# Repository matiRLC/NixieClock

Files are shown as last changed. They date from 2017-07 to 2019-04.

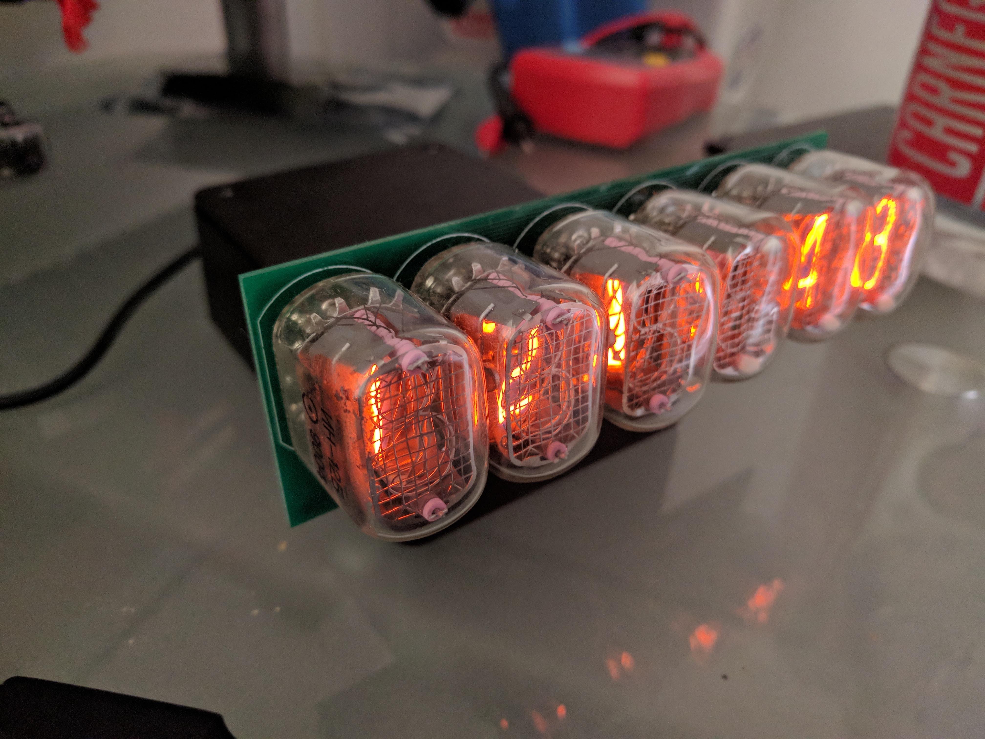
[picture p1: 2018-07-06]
docs/nixieclock5.jpg

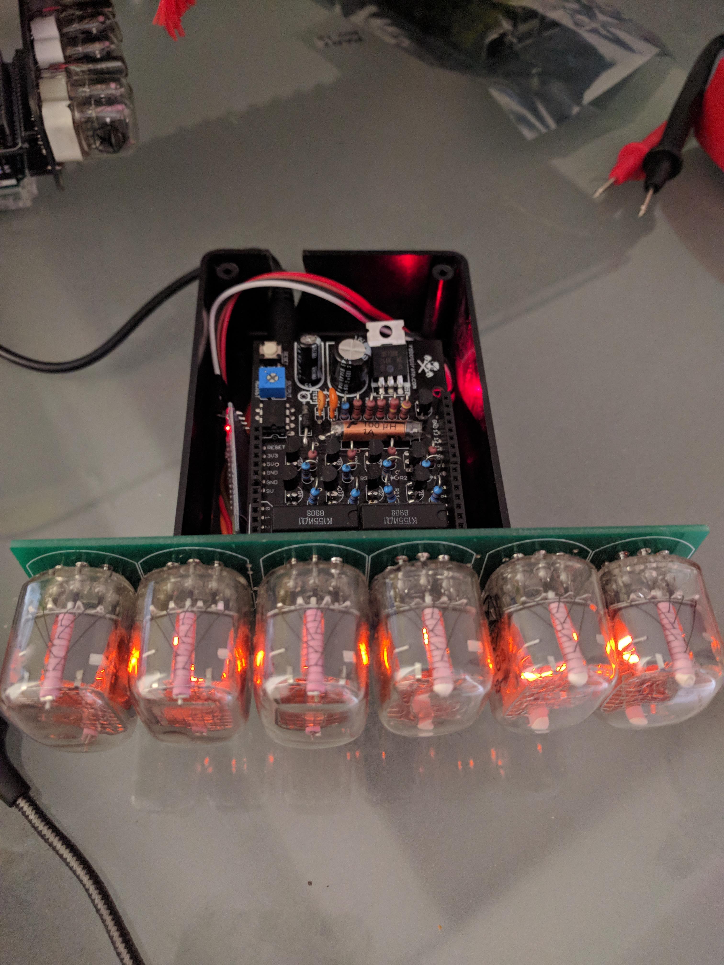
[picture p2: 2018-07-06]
docs/nixieclock4.jpg

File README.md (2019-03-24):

View this project on [CADLAB.io](https://cadlab.io/project/1200). 

# NixieClock
Nixie Tube Clock based project based on existing code and boards by Ogilumen and RobotPirate

The current project uses an Arduino Uno and the Arduinix Shield from RobotPirate. The code is an extension of the sample code
provided by the latter. The PCB for 6 nixie tubes was designed based on the .pdf schematic available in [Arduinix](http://www.arduinix.com).

As of 2019, the current design uses a bluetooth module (HC-06 or HM-10). The use of HM-10 was chosen since it's a Bluetooth 4.0+ module that allows it to work with both Android and iOS apps.

The iOS app was implemented with the work from [hoiberg](https://github.com/hoiberg/HM10-BluetoothSerial-iOS) as a template. His explanation of his project can be found [here](http://www.hangar42.nl/hm10).

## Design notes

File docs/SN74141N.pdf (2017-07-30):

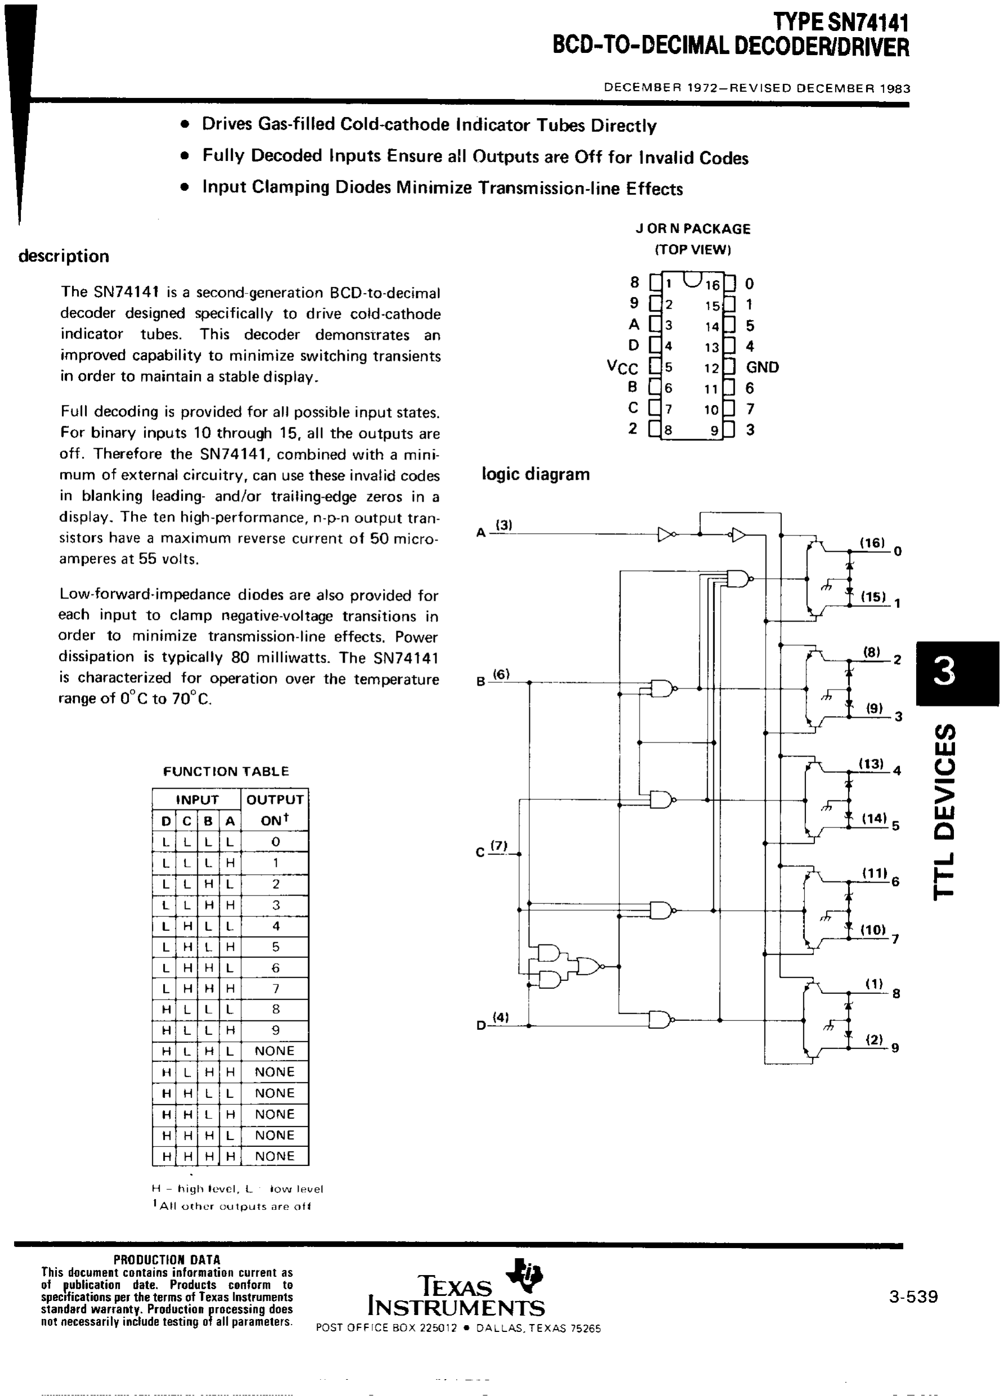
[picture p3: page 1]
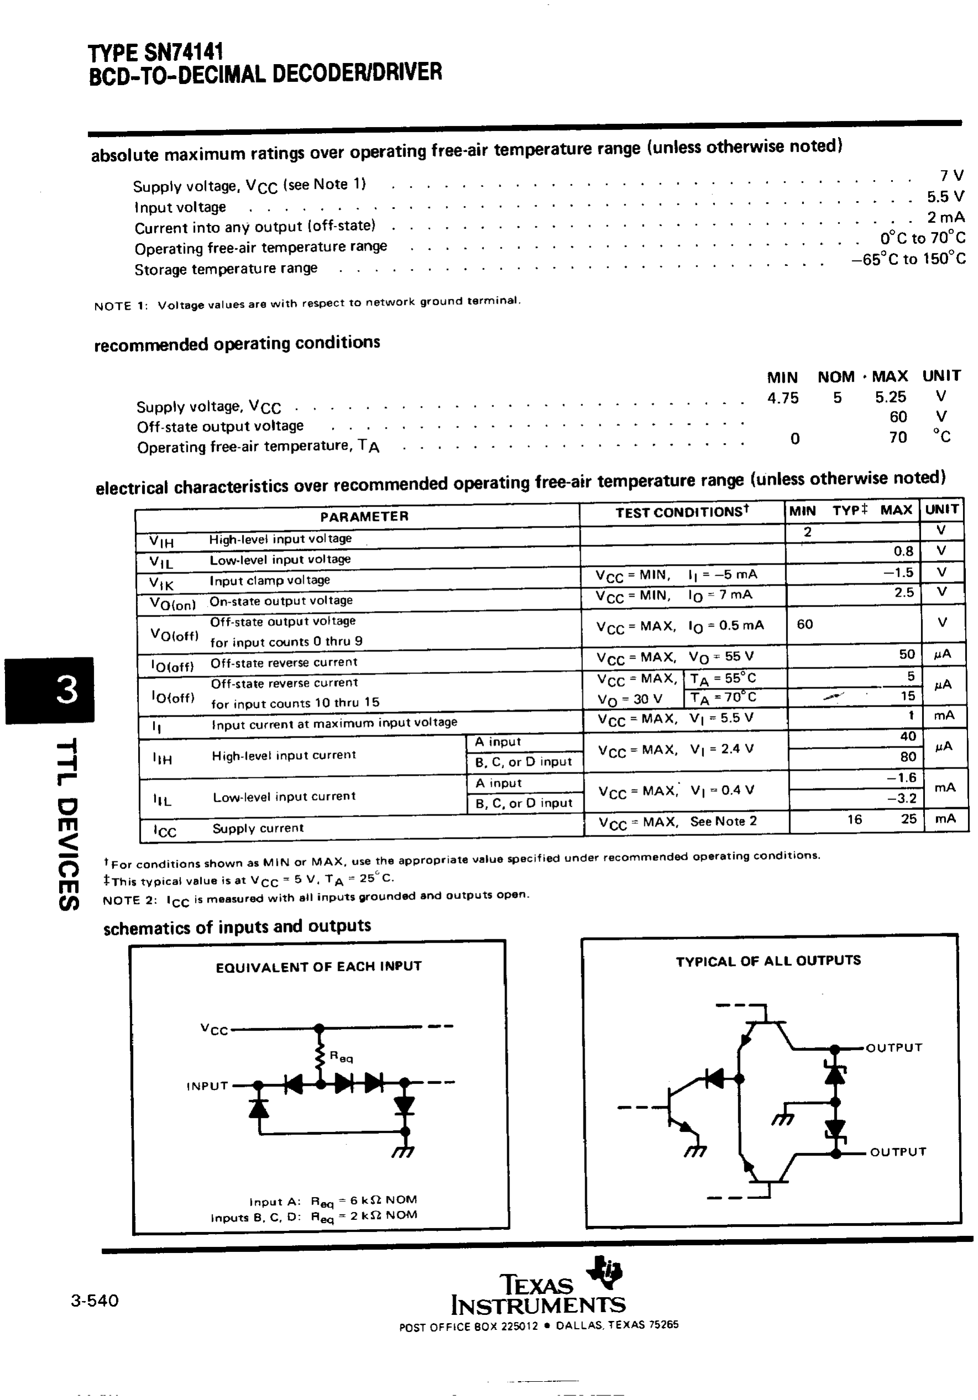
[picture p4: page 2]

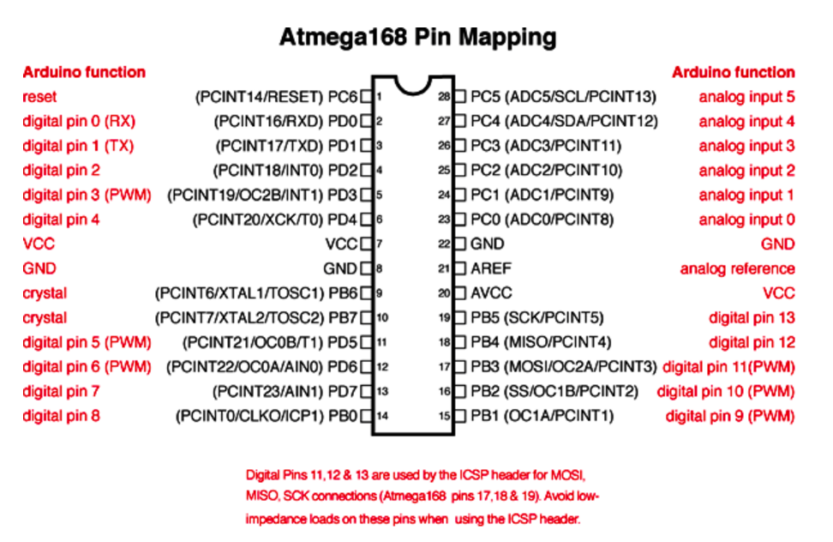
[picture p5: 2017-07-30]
docs/Arduino Atmel pinout.png

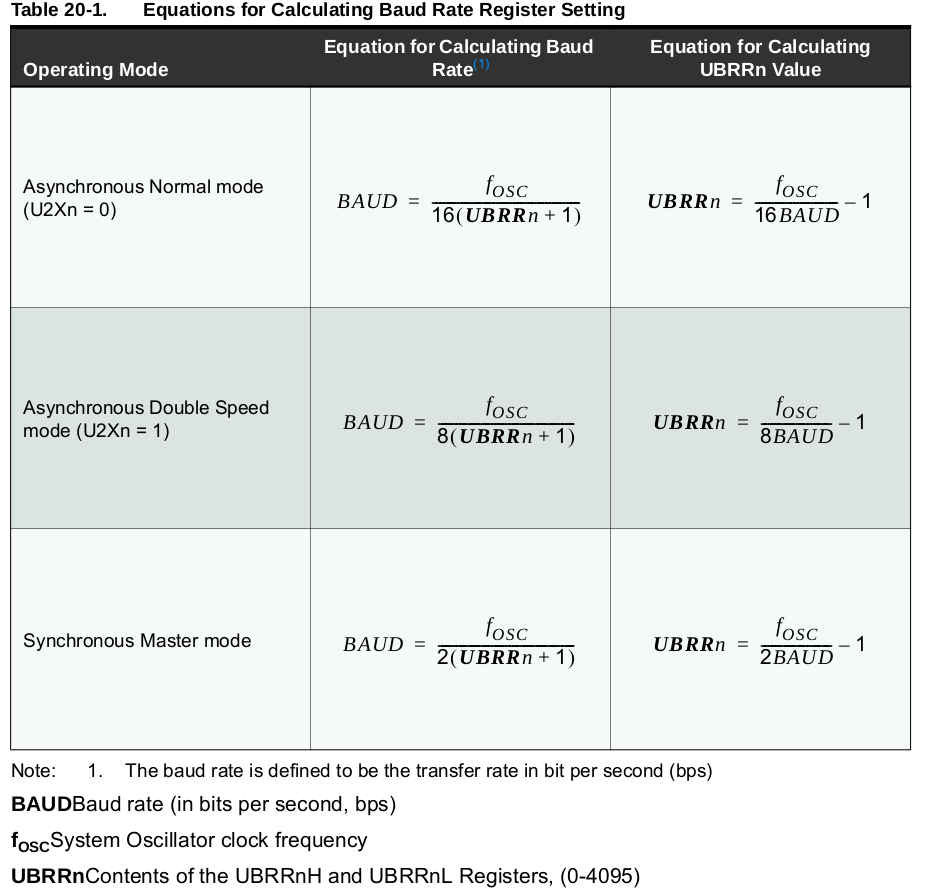
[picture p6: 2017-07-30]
docs/Baud Rates Register Setting.png

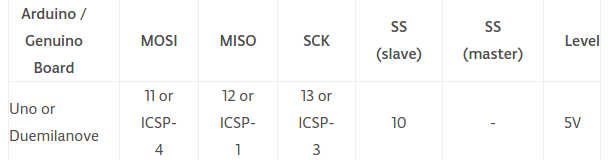
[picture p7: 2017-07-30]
docs/SPI Pins.png

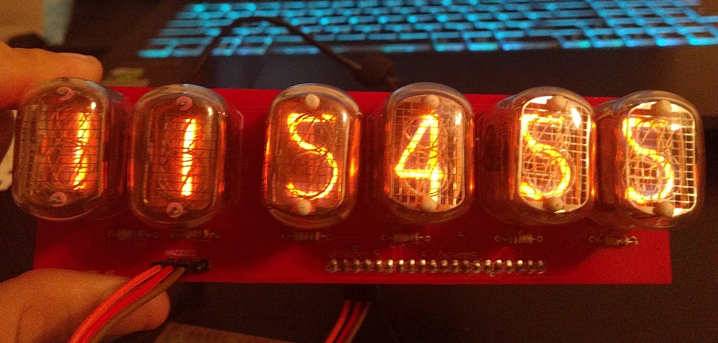
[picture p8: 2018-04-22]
docs/nixieclock_teaser.jpg

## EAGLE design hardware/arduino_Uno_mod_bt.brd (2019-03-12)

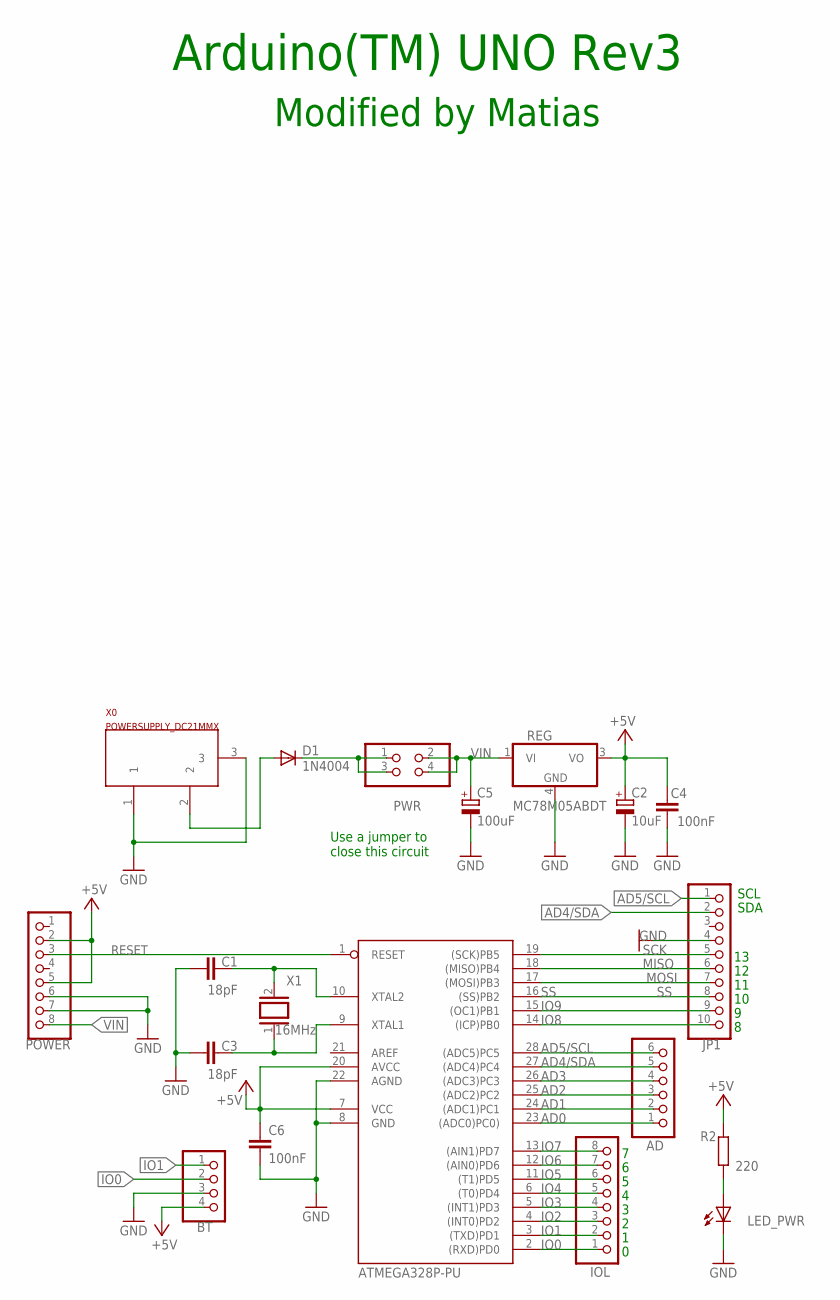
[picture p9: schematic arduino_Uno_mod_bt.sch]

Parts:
AD: 6x1F-H8.5; 1X06
BT: PINHD-1X4/90; 1X04/90
C1, C3: 18pF; C025-025X050
C2: 10uF; E2,5-5
C4, C6: 100nF; C025-025X050
C5: 100uF; E2-5
D1: 1N4004; DO41-10
IOL: 8x1F-H8.5; 1X08
JP1: PINHD-1X10; 1X10
LED_PWR: LED3MM
POWER: 8x1F-H8.5; 1X08
PWR: PINHD-2X2; 2X02
R2: 220; R1206
REG: MC78M05ABDT; DPACK_3
X0: POWERSUPPLY_DC21MMX; POWERSUPPLY_DC-21MM
X1: 16MHz; QS
ZU4: ATMEGA328P-PU; DIL28-3

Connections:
+5V: BT.4, C2.+, C4.2, C6.1, POWER.2, POWER.5, R2.2, REG.3 (VO), ZU4.7 (VCC), ZU4.20 (AVCC)
AD0: AD.1, ZU4.23 ((ADC0)PC0))
AD1: AD.2, ZU4.24 ((ADC1)PC1)
AD2: AD.3, ZU4.25 ((ADC2)PC2)
AD3: AD.4, ZU4.26 ((ADC3)PC3)
AD4/SDA: AD.5, JP1.2, ZU4.27 ((ADC4)PC4)
AD5/SCL: AD.6, JP1.1, ZU4.28 ((ADC5)PC5)
GND: BT.3, C1.1, C2.-, C3.1, C4.1, C5.-, C6.2, JP1.4, LED_PWR.K (C), POWER.6, POWER.7, REG.4 (GND), X0.1, X0.3, ZU4.8 (GND), ZU4.22 (AGND)
IN: D1.A, X0.2
IO0: BT.2, IOL.1, ZU4.2 ((RXD)PD0)
IO1: BT.1, IOL.2, ZU4.3 ((TXD)PD1)
IO2: IOL.3, ZU4.4 ((INT0)PD2)
IO3: IOL.4, ZU4.5 ((INT1)PD3)
IO4: IOL.5, ZU4.6 ((T0)PD4)
IO5: IOL.6, ZU4.11 ((T1)PD5)
IO6: IOL.7, ZU4.12 ((AIN0)PD6)
IO7: IOL.8, ZU4.13 ((AIN1)PD7)
IO8: JP1.10, ZU4.14 ((ICP)PB0)
IO9: JP1.9, ZU4.15 ((OC1)PB1)
MISO: JP1.6, ZU4.18 ((MISO)PB4)
MOSI: JP1.7, ZU4.17 ((MOSI)PB3)
unnamed: C3.2, X1.1, ZU4.9 (XTAL1)
unnamed: LED_PWR.A, R2.1
unnamed: D1.C, PWR.1, PWR.3
RESET: POWER.3, ZU4.1 (RESET)
SCK: JP1.5, ZU4.19 ((SCK)PB5)
SS: JP1.8, ZU4.16 ((SS)PB2)
VIN: C5.+, POWER.8, PWR.2, PWR.4, REG.1 (VI)
XTAL2: C1.2, X1.2, ZU4.10 (XTAL2)

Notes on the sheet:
Arduino(TM) UNO Rev3
SDA
SCL
Modified by Matias
Use a jumper to close this circuit

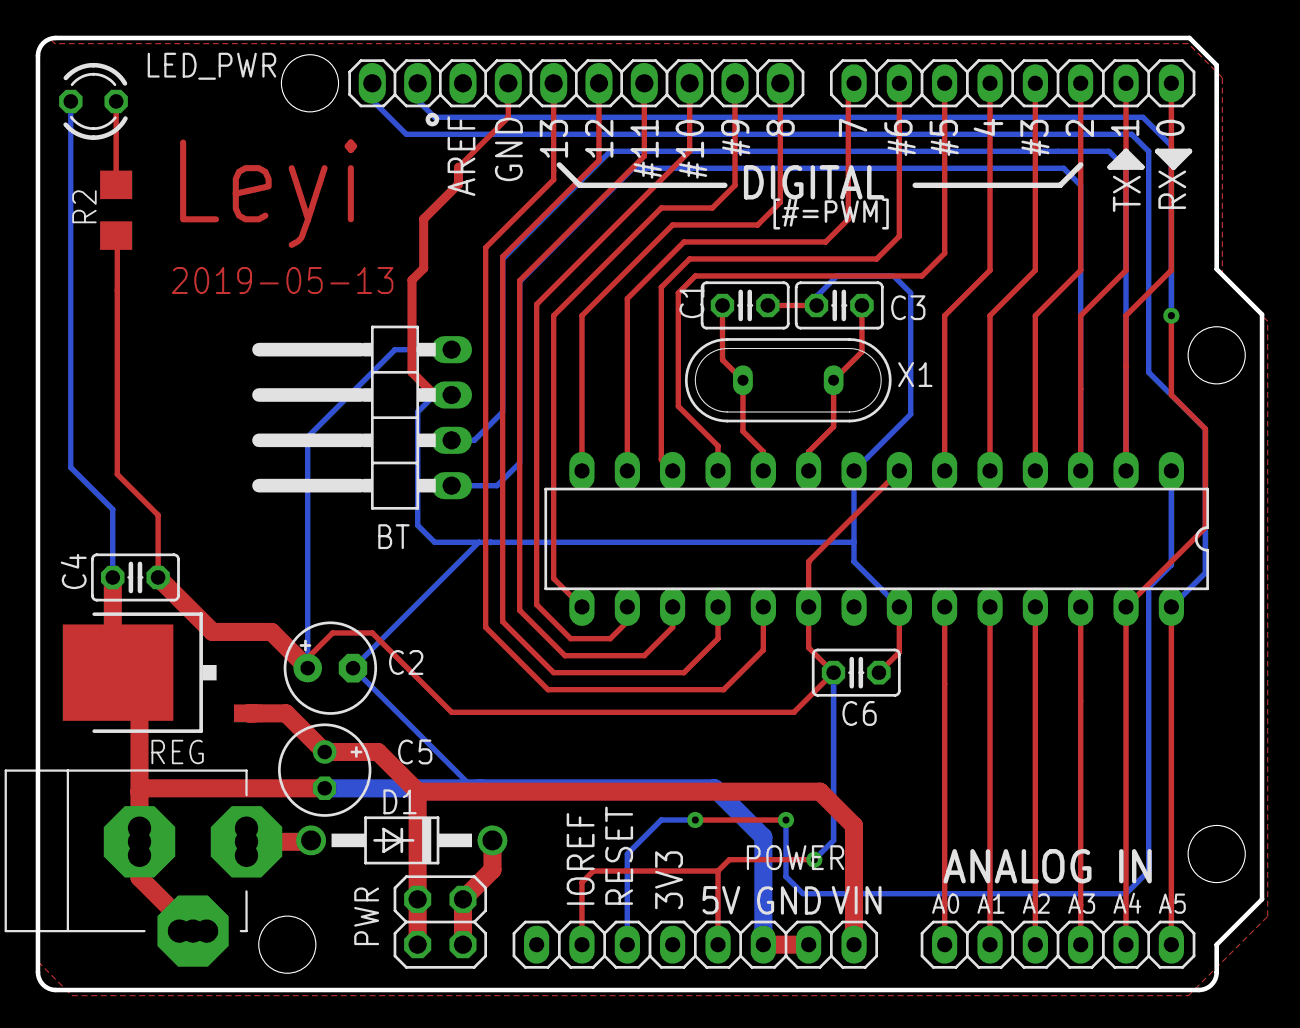
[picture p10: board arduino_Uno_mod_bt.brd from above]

Board: 2 copper layers, 68.6 x 53.3 mm, 19 parts (0 on the bottom side), 29 nets.

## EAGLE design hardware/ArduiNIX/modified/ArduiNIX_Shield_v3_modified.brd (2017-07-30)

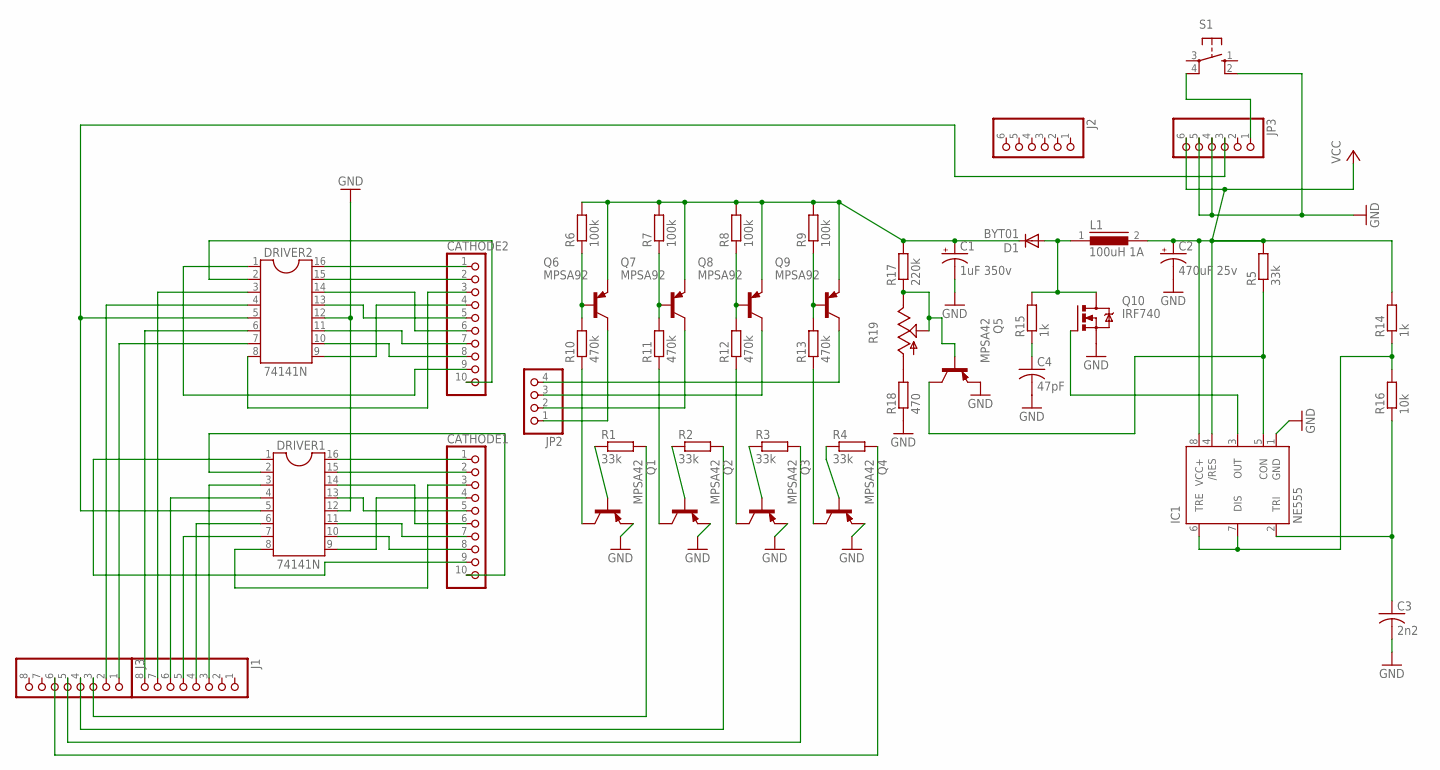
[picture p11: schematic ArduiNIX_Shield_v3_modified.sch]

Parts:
C1: 1uF 350v; E2,5-7
C2: 470uF 25v; E5-10,5
C3: 2n2; C050-024X044
C4: 47pF; C075-032X103
CATHODE1, CATHODE2: PINHD-1X10; 1X10
D1: BYT01; F126-10
DRIVER1, DRIVER2: 74141N; DIL16
IC1: NE555; DIL-08
J1, J3: PINHD-1X8; 1X08
J2: PINHD-1X6; 1X06
JP2: PINHD-1X4; 1X04
JP3: PINHD-1X6; 1X06
L1: 100uH 1A; MESC26
Q1, Q2, Q3, Q4, Q5: MPSA42; TO92-CBE
Q6, Q7, Q8, Q9: MPSA92; TO92-CBE
Q10: IRF740; TO220BV
R1, R2, R3, R4, R5: 33k; R1206
R6, R7, R8, R9: 100k; R1206
R10, R11, R12, R13: 470k; R1206
R14, R15: 1k; R1206
R16: 10k; R1206
R17: 220k; R1206
R18: 470; R1206
R19: TRIM_US-B25P; B25P
S1: 10-XX; B3F-10XX

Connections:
5V: DRIVER1.5, DRIVER2.5, JP3.3
GND: C1.-, C2.-, C3.2, C4.2, DRIVER1.12, DRIVER2.12, IC1.1 (GND), JP3.4, JP3.5, Q1.E, Q2.E, Q3.E, Q4.E, Q5.E, Q10.S, R18.1, S1.2 (S1)
unnamed: CATHODE2.2, DRIVER2.15
unnamed: Q6.B, R6.1, R10.2
unnamed: CATHODE2.3, DRIVER2.8
unnamed: DRIVER1.3, J1.3
unnamed: DRIVER1.6, J1.4
unnamed: DRIVER1.7, J1.5
unnamed: CATHODE1.10, DRIVER1.2
unnamed: C4.1, R15.1
unnamed: DRIVER2.6, J1.8
unnamed: DRIVER2.7, J3.1
unnamed: DRIVER2.3, J1.7
unnamed: CATHODE2.4, DRIVER2.9
unnamed: CATHODE2.5, DRIVER2.13
unnamed: CATHODE2.6, DRIVER2.14
unnamed: CATHODE2.7, DRIVER2.11
unnamed: CATHODE2.8, DRIVER2.10
unnamed: CATHODE2.9, DRIVER2.1
unnamed: CATHODE2.10, DRIVER2.2
unnamed: C1.+, D1.C, Q6.E, Q7.E, Q8.E, Q9.E, R6.2, R7.2, R8.2, R9.2, R17.2
unnamed: CATHODE1.2, DRIVER1.15
unnamed: CATHODE1.6, DRIVER1.14
unnamed: CATHODE2.1, DRIVER2.16
unnamed: DRIVER2.4, J3.2
unnamed: DRIVER1.4, J1.6
unnamed: CATHODE1.4, DRIVER1.9
unnamed: CATHODE1.8, DRIVER1.10
unnamed: CATHODE1.7, DRIVER1.11
unnamed: CATHODE1.5, DRIVER1.13
unnamed: CATHODE1.9, DRIVER1.1
unnamed: Q1.B, R1.1
unnamed: Q2.B, R2.1
unnamed: Q3.B, R3.1
unnamed: J3.3, R1.2
unnamed: J3.4, R2.2
unnamed: J3.5, R3.2
unnamed: Q1.C, R10.1
unnamed: Q2.C, R11.1
unnamed: Q3.C, R12.1
unnamed: JP2.1, Q6.C
unnamed: JP2.2, Q7.C
unnamed: JP2.3, Q8.C
unnamed: Q7.B, R7.1, R11.2
unnamed: Q8.B, R8.1, R12.2
unnamed: CATHODE1.3, DRIVER1.8
unnamed: D1.A, L1.1, Q10.D, R15.2
unnamed: Q5.B, R17.1, R19.E, R19.S
unnamed: R18.2, R19.A
unnamed: Q9.B, R9.1, R13.2
unnamed: IC1.6 (TRE), IC1.7 (DIS), R14.1, R16.2
unnamed: JP2.4, Q9.C
unnamed: JP3.1, S1.4 (P1)
unnamed: IC1.3 (OUT), Q10.G
unnamed: IC1.5 (CON), Q5.C, R5.1
unnamed: C3.1, IC1.2 (TRI), R16.1
unnamed: Q4.C, R13.1
unnamed: Q4.B, R4.1
unnamed: J3.6, R4.2
unnamed: CATHODE1.1, DRIVER1.16
VCC: C2.+, IC1.4 (/RES), IC1.8 (VCC+), JP3.6, L1.2, R5.2, R14.2

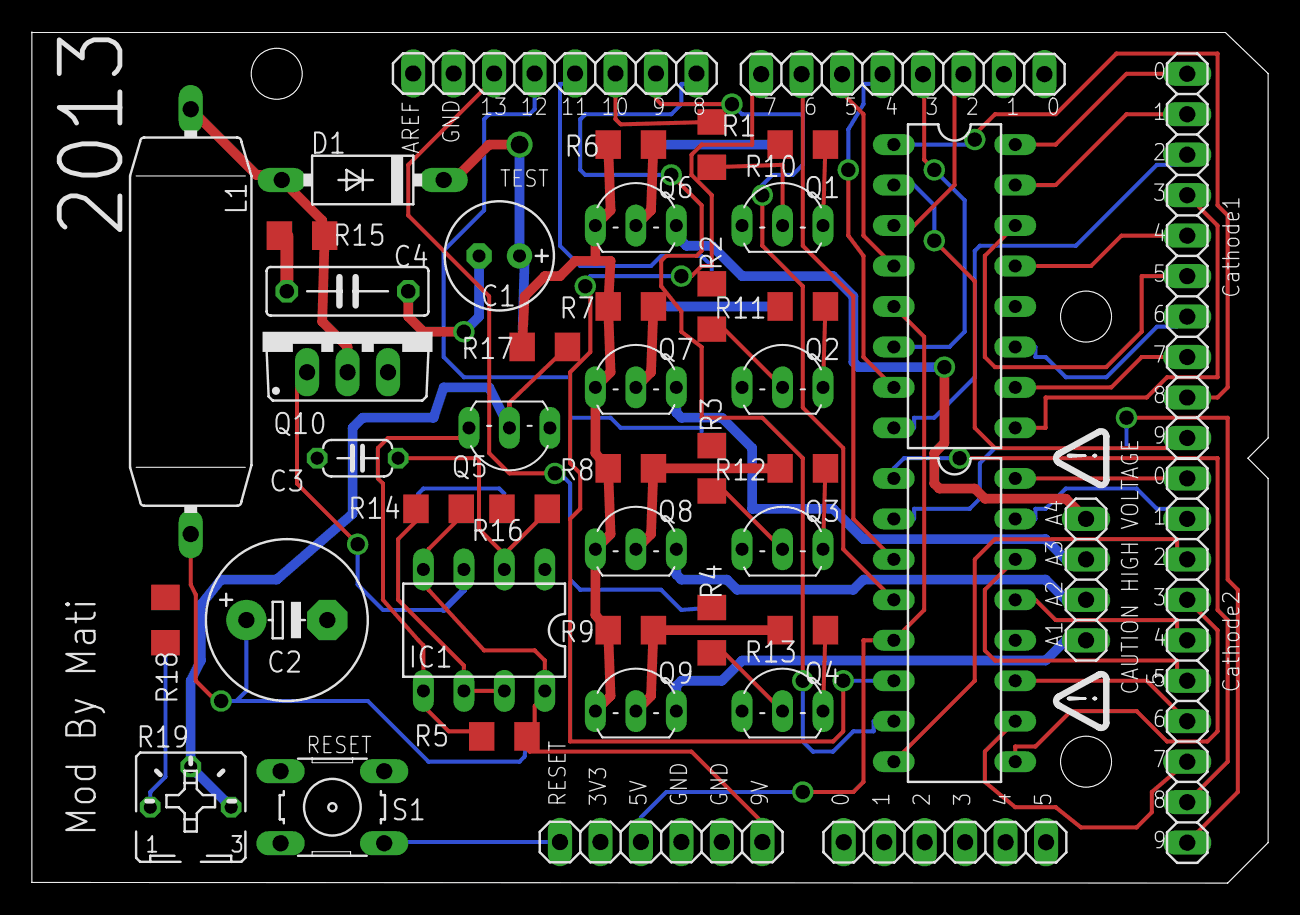
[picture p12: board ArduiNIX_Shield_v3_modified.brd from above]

Board: 2 copper layers, 77.6 x 53.4 mm, 46 parts (0 on the bottom side), 61 nets.

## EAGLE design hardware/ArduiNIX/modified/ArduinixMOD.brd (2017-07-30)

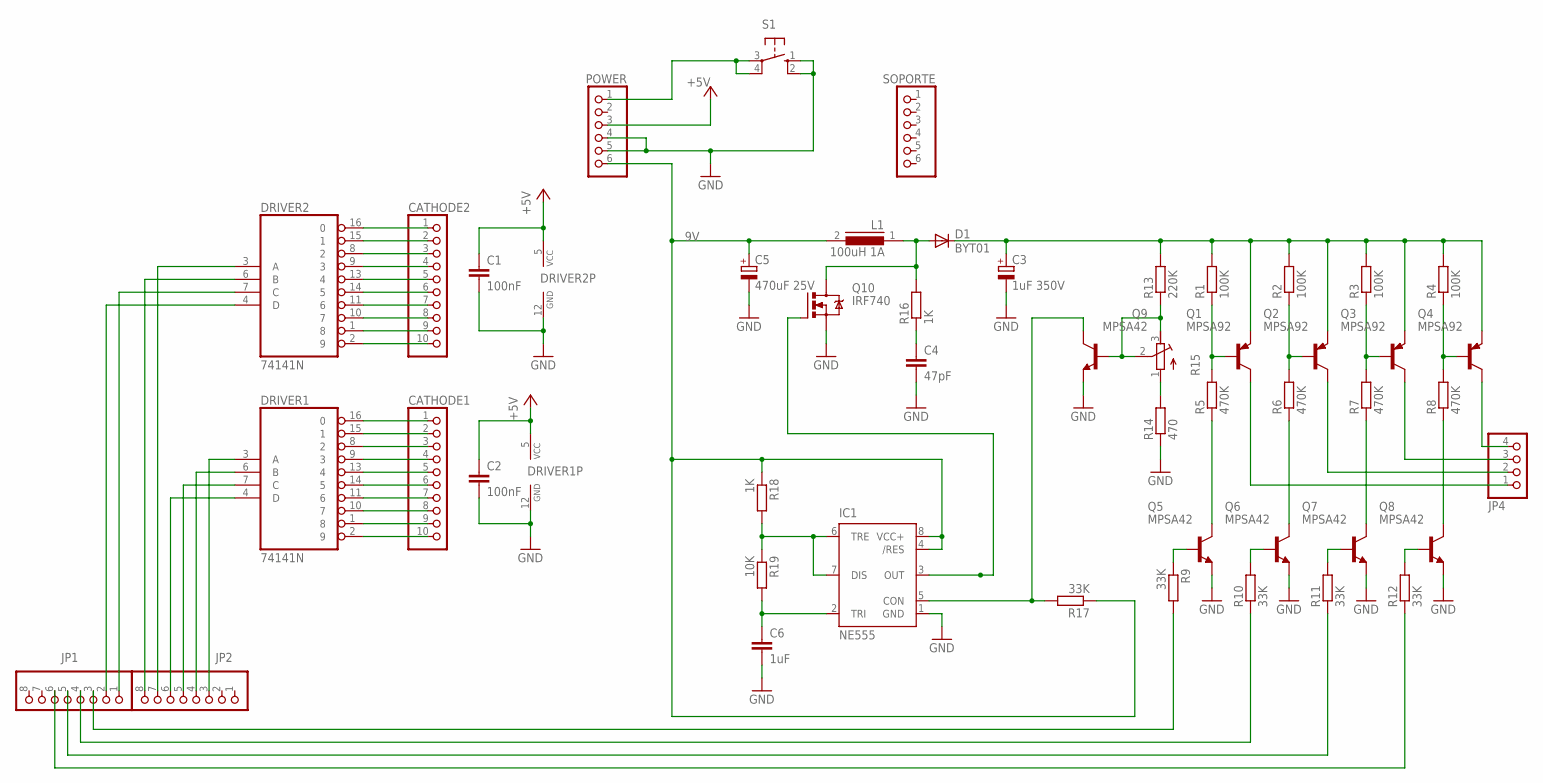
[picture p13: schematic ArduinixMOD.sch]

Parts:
C1, C2: 100nF; C025-025X050
C3: 1uF 350V; E2,5-7
C4: 47pF; C025-025X050
C5: 470uF 25V; E5-10,5
C6: 1uF; C025-025X050
CATHODE1, CATHODE2: PINHD-1X10; 1X10
D1: BYT01; F126-10
DRIVER1, DRIVER2: 74141N; DIL16
IC1: NE555; DIL-08
JP1, JP2: PINHD-1X8; 1X08
JP4: PINHD-1X4; 1X04
L1: 100uH 1A; MESC26
POWER: PINHD-1X6; 1X06
Q1, Q2, Q3, Q4: MPSA92; TO92-CBE
Q5, Q6, Q7, Q8, Q9: MPSA42; TO92-EBC
Q10: IRF740; TO220BV
R1, R2, R3, R4: 100K; R1206
R5, R6, R7, R8: 470K; R1206
R9, R10, R11, R12, R17: 33K; R1206
R13: 220K; R1206
R14: 470; R1206
R15: R-TRIMM64W; RTRIM64W
R16, R18: 1K; R1206
R19: 10K; R1206
S1: 10-XX; B3F-10XX
SOPORTE: PINHD-1X6; 1X06

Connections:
9V: C5.+, IC1.4 (/RES), IC1.8 (VCC+), L1.2, POWER.6, R17.1, R18.1
+5V: C1.1, C2.1, DRIVER1.5 (VCC), DRIVER2.5 (VCC), POWER.3
GND: C1.2, C2.2, C3.-, C4.2, C5.-, C6.2, DRIVER1.12 (GND), DRIVER2.12 (GND), IC1.1 (GND), POWER.4, POWER.5, Q5.E, Q6.E, Q7.E, Q8.E, Q9.E, Q10.S, R14.1, S1.1 (S), S1.2 (S1)
unnamed: CATHODE2.9, DRIVER2.1 (8)
unnamed: CATHODE2.10, DRIVER2.2 (9)
unnamed: DRIVER2.3 (A), JP2.7
unnamed: DRIVER2.4 (D), JP1.2
unnamed: DRIVER2.6 (B), JP2.8
unnamed: DRIVER2.7 (C), JP1.1
unnamed: CATHODE2.3, DRIVER2.8 (2)
unnamed: CATHODE2.4, DRIVER2.9 (3)
unnamed: CATHODE2.8, DRIVER2.10 (7)
unnamed: CATHODE2.7, DRIVER2.11 (6)
unnamed: DRIVER1.4 (D), JP2.6
unnamed: CATHODE2.5, DRIVER2.13 (4)
unnamed: CATHODE2.6, DRIVER2.14 (5)
unnamed: CATHODE2.2, DRIVER2.15 (1)
unnamed: CATHODE2.1, DRIVER2.16 (0)
unnamed: DRIVER1.6 (B), JP2.4
unnamed: DRIVER1.7 (C), JP2.5
unnamed: CATHODE1.3, DRIVER1.8 (2)
unnamed: CATHODE1.9, DRIVER1.1 (8)
unnamed: CATHODE1.10, DRIVER1.2 (9)
unnamed: DRIVER1.3 (A), JP2.3
unnamed: CATHODE1.4, DRIVER1.9 (3)
unnamed: CATHODE1.8, DRIVER1.10 (7)
unnamed: CATHODE1.7, DRIVER1.11 (6)
unnamed: CATHODE1.5, DRIVER1.13 (4)
unnamed: CATHODE1.6, DRIVER1.14 (5)
unnamed: CATHODE1.2, DRIVER1.15 (1)
unnamed: CATHODE1.1, DRIVER1.16 (0)
unnamed: Q1.B, R1.1, R5.2
unnamed: Q2.B, R2.1, R6.2
unnamed: Q3.B, R3.1, R7.2
unnamed: Q4.B, R4.1, R8.2
unnamed: D1.A, L1.1, Q10.D, R16.2
unnamed: JP4.2, Q2.C
unnamed: JP1.3, R9.2
unnamed: JP4.1, Q1.C
unnamed: JP1.4, R10.1
unnamed: JP4.3, Q3.C
unnamed: JP4.4, Q4.C
unnamed: Q5.C, R5.1
unnamed: Q6.C, R6.1
unnamed: Q5.B, R9.1
unnamed: Q6.B, R10.2
unnamed: Q7.B, R11.2
unnamed: Q7.C, R7.1
unnamed: Q8.C, R8.1
unnamed: Q8.B, R12.2
unnamed: JP1.5, R11.1
unnamed: JP1.6, R12.1
unnamed: Q9.B, R13.1, R15.2 (S), R15.3 (E)
unnamed: C4.1, R16.1
unnamed: R14.2, R15.1 (A)
unnamed: C3.+, D1.C, Q1.E, Q2.E, Q3.E, Q4.E, R1.2, R2.2, R3.2, R4.2, R13.2
unnamed: IC1.6 (TRE), IC1.7 (DIS), R18.2, R19.1
unnamed: C6.1, IC1.2 (TRI), R19.2
unnamed: POWER.1, S1.3, S1.4 (P1)
unnamed: IC1.5 (CON), Q9.C, R17.2
unnamed: IC1.3 (OUT), Q10.G

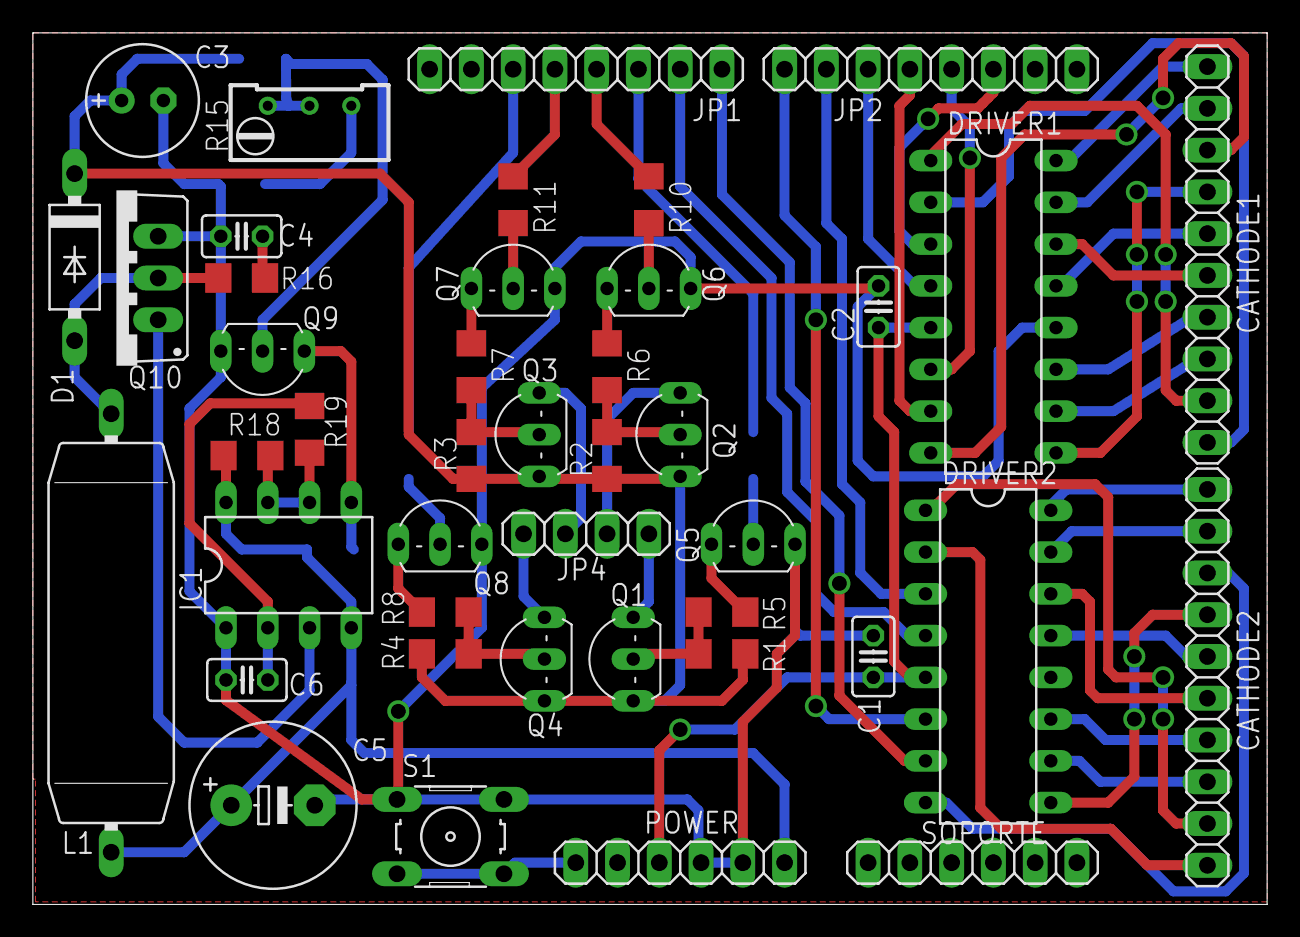
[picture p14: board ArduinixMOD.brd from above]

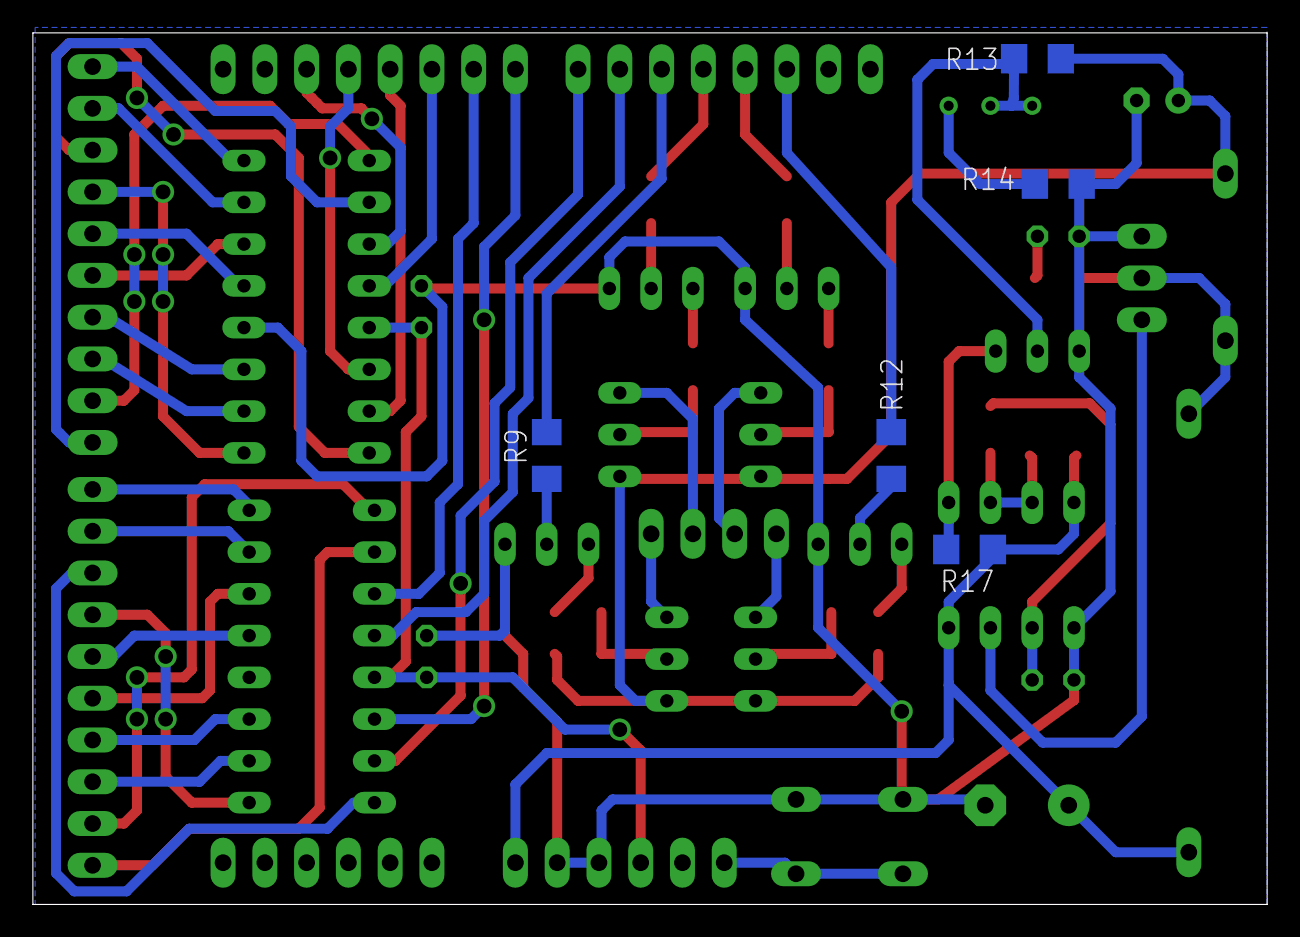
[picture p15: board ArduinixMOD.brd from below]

Board: 2 copper layers, 75.1 x 53.0 mm, 48 parts (5 on the bottom side), 61 nets.

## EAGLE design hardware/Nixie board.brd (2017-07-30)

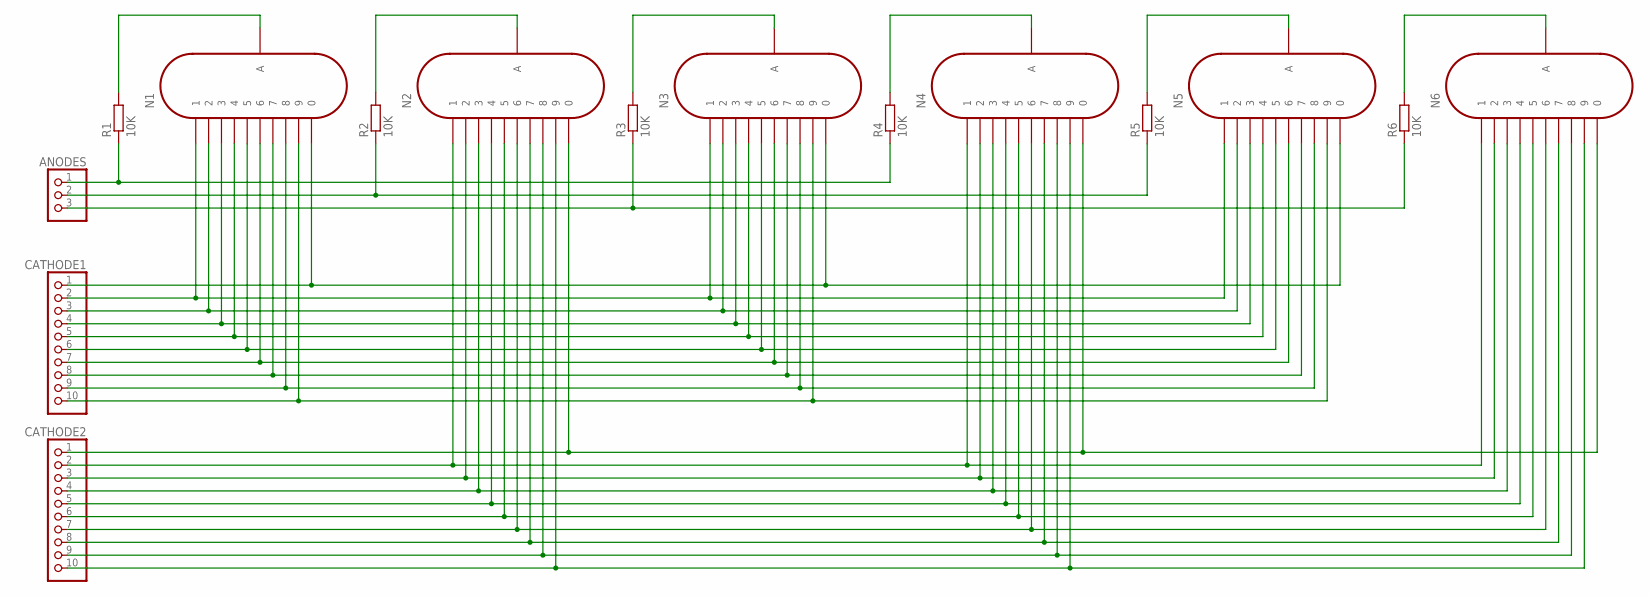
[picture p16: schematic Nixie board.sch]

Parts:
ANODES: PINHD-1X3; 1X03
CATHODE1, CATHODE2: PINHD-1X10; 1X10
N1, N2, N3, N4, N5, N6: IN-12A; IN-12
R1, R2, R3, R4, R5, R6: 10K; 0207/10

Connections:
unnamed: N1.A, R1.2
unnamed: ANODES.1, R1.1, R4.1
unnamed: N4.A, R4.2
unnamed: ANODES.2, R2.1, R5.1
unnamed: N5.A, R5.2
unnamed: N2.A, R2.2
unnamed: ANODES.3, R3.1, R6.1
unnamed: N6.A, R6.2
unnamed: N3.A, R3.2
unnamed: CATHODE1.1, N1.0, N3.0, N5.0
unnamed: CATHODE1.2, N1.1, N3.1, N5.1
unnamed: CATHODE1.3, N1.2, N3.2, N5.2
unnamed: CATHODE1.4, N1.3, N3.3, N5.3
unnamed: CATHODE1.5, N1.4, N3.4, N5.4
unnamed: CATHODE1.6, N1.5, N3.5, N5.5
unnamed: CATHODE1.7, N1.6, N3.6, N5.6
unnamed: CATHODE1.8, N1.7, N3.7, N5.7
unnamed: CATHODE1.9, N1.8, N3.8, N5.8
unnamed: CATHODE1.10, N1.9, N3.9, N5.9
unnamed: CATHODE2.1, N2.0, N4.0, N6.0
unnamed: CATHODE2.2, N2.1, N4.1, N6.1
unnamed: CATHODE2.3, N2.2, N4.2, N6.2
unnamed: CATHODE2.4, N2.3, N4.3, N6.3
unnamed: CATHODE2.5, N2.4, N4.4, N6.4
unnamed: CATHODE2.6, N2.5, N4.5, N6.5
unnamed: CATHODE2.7, N2.6, N4.6, N6.6
unnamed: CATHODE2.8, N2.7, N4.7, N6.7
unnamed: CATHODE2.9, N2.8, N4.8, N6.8
unnamed: CATHODE2.10, N2.9, N4.9, N6.9

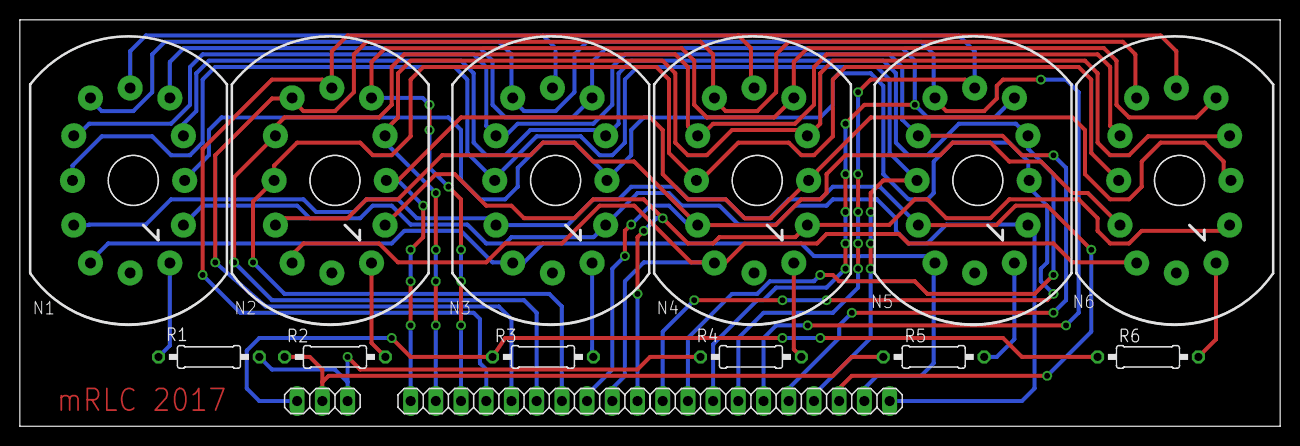
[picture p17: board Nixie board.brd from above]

Board: 2 copper layers, 127.0 x 40.9 mm, 15 parts (0 on the bottom side), 29 nets.

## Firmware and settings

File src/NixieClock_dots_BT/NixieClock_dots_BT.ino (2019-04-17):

// fading transitions sketch for 6-tube board with default connections.
// based on 6-tube sketch by Emblazed

// 09/03/2010 - Added Poxin's 12 hour setting for removing 00 from hours when set to 12 hour time
// 06/16/2011 - 4-tube-itized by Dave B.
// 08/19/2011 - modded for six bulb board, hours, minutes, seconds by Brad L.
// 01/28/2013 - expanded to 8 digit crossfade by Brad L.
// 12/04/2014 - First V2 standardization version by Brad L. 
// 01/07/2015 - Code Revision by Jeremy Howa
// 05/17/2015 - Added light sensor support to auto dim tubes.  Added neopixel driver - Brad L. 
// 12/30/2016 - commented out neopixel code in case user hasn't included that library in local files. Set as standard 6xIN17, 4xINS1 codebase

// 19/08/2018 - adapted original code for a more stripped down version of just 6 bulbs + colons, matiasquintana.com
// 03/02/2019 - add the BT section from older code, matiasquintana.com

/** Pin mapping for Arduino UNO, AtSET_TIMEmega328P
 * ARDUINO UNO    Atmega328P  Used by
 *     A3            PC03     Bluetooth (TX)
 *     A4            PC04     Bluetooth (RX)
 *     PIN2          PD02     Nixie Driver
 *     PIN3          PD03     Nixie Driver
 *     PIN4          PD04     Nixie Driver
 *     PIN5          PD05     Nixie Driver
 *     PIN6          PD06     Nixie Driver
 *     PIN7          PD07     Nixie Driver
 *     PIN8          PB00     Nixie Driver
 *     PIN9          PB01     Nixie Driver
 *    PIN10          PB02     Nixie Driver
 *    PIN11          PB03     Nixie Driver
 *    PIN12          PB04     Nixie Driver
 */

#include <stdio.h>
#include <stdlib.h>

// DEFINE
#define _DEBUG 0
long MINS  = 60;         // 60 Seconds in a Min.
long HOURS = 60 * MINS;  // 60 Mins in an hour.
long DAYS  = 24 * HOURS; // 24 Hours in a day. > Note: change the 24 to a 12 for non military time.

long runTime = 0; // Time from when we started.

// default time sets. clock will start at 12:34:56.  This is so we can count the correct order of tubes.
long clockHourSet;
long clockMinSet;
//long clockSecSet  = 00;

int HourButtonPressed = false;
int MinButtonPressed = false;

String data = ""; // initialize received message

/**
 * SN74141: True Table
 * D  C  B  A  #     
 * L, L, L, L  9
 * L, L, L, H  8
 * L, L, H, L  7
 * L, L, H, H  6
 * L, H, L, L  5
 * L, H, L, H  4
 * L, H, H, L  3
 * L, H, H, H  2
 * H, L, L, L  1
 * H, L, L, H  0
 */

// SN74141 (1)
int ledPin_0_a = 2;                
int ledPin_0_b = 3;
int ledPin_0_c = 4;
int ledPin_0_d = 5;

// SN74141 (2)
int ledPin_1_a = 6;                
int ledPin_1_b = 7;
int ledPin_1_c = 8;
int ledPin_1_d = 9;

// anode pins
int ledPin_a_1 = 10;
int ledPin_a_2 = 11;
int ledPin_a_3 = 12;
int ledPin_a_4 = 13;

/**
 * setup()
 * Purpose: IO initialization and debugging flag set
 */
void setup() {
    Serial.begin(9600); // so BT can retrieve data
    
    pinMode(ledPin_0_a, OUTPUT);      
    pinMode(ledPin_0_b, OUTPUT);      
    pinMode(ledPin_0_c, OUTPUT);      
    pinMode(ledPin_0_d, OUTPUT);    
  
    pinMode(ledPin_1_a, OUTPUT);      
    pinMode(ledPin_1_b, OUTPUT);      
    pinMode(ledPin_1_c, OUTPUT);      
    pinMode(ledPin_1_d, OUTPUT);      
  
    pinMode(ledPin_a_1, OUTPUT);      
    pinMode(ledPin_a_2, OUTPUT);      
    pinMode(ledPin_a_3, OUTPUT);   
    pinMode(ledPin_a_4, OUTPUT);    
 
    // NOTE: Grounding on pints 14 and 15 will set the Hour and Mins.
    pinMode(14, INPUT); // set the virtual pin 14 (pin 0 on the analog inputs )  SET HOURS up
    digitalWrite(14, HIGH); // set pin 14 as a pull up resistor.

    pinMode(15, INPUT); // set the virtual pin 15 (pin 1 on the analog inputs )  SET MINUTES up
    digitalWrite(15, HIGH); // set pin 15 as a pull up resistor.

//    digitalWrite(ledPin_a_1, HIGH); // TEST
}   

/**
 * DisplayNumberSet
 * Purpose: Looks up the truth table and opens the correct outs from the arduino
 * to light the numbers given to this funciton (num1,num2), on a 6 nixie bulb setup. 
 * @var anod anode number
 * @var num1 bulb 1 valueclockMinSet
 * @var num2 bulb 2 value
 **/
void DisplayNumberSet(int anod, int num2, int num1, int delayVal) {
    int anodPin;
    int a,b,c,d;  
    
    // set defaults.
    a = 0; b = 0; c = 0; d = 0; // will display a zero.
    anodPin = ledPin_a_1;       // default on first anod.

    // Select what anod to fire.
    switch (anod) {
        case 0: anodPin = ledPin_a_1; break;
        case 1: anodPin = ledPin_a_2; break;
        case 2: anodPin = ledPin_a_3; break;
        case 3: anodPin = ledPin_a_4; break;
    }
    
    // Load the a,b,c,d.. to send to the SN74141 IC (1)
    switch (num1) {
        case 9: a = 0; b = 0; c = 0; d = 0; break;
        case 8: a = 1; b = 0; c = 0; d = 0; break;
        case 7: a = 0; b = 1; c = 0; d = 0; break;
        case 6: a = 1; b = 1; c = 0; d = 0; break;
        case 5: a = 0; b = 0; c = 1; d = 0; break;
        case 4: a = 1; b = 0; c = 1; d = 0; break;
        case 3: a = 0; b = 1; c = 1; d = 0; break;
        case 2: a = 1; b = 1; c = 1; d = 0; break;
        case 1: a = 0; b = 0; c = 0; d = 1; break;
        case 0: a = 1; b = 0; c = 0; d = 1; break;
    }  
  
    // Write to output pins.
    digitalWrite(ledPin_0_d, d);
    digitalWrite(ledPin_0_c, c);
    digitalWrite(ledPin_0_b, b);
    digitalWrite(ledPin_0_a, a);

    // Load the a,b,c,d.. to send to the SN74141 IC (2)
    switch (num2) {
        case 9: a = 0; b = 0; c = 0; d = 0; break;
        case 8: a = 1; b = 0; c = 0; d = 0; break;
        case 7: a = 0; b = 1; c = 0; d = 0; break;
        case 6: a = 1; b = 1; c = 0; d = 0; break;
        case 5: a = 0; b = 0; c = 1; d = 0; break;
        case 4: a = 1; b = 0; c = 1; d = 0; break;
        case 3: a = 0; b = 1; c = 1; d = 0; break;
        case 2: a = 1; b = 1; c = 1; d = 0; break;
        case 1: a = 0; b = 0; c = 0; d = 1; break;
        case 0: a = 1; b = 0; c = 0; d = 1; break;
    }
  
    // Write to output pins
    digitalWrite(ledPin_1_d, d);
    digitalWrite(ledPin_1_c, c);
    digitalWrite(ledPin_1_b, b);
    digitalWrite(ledPin_1_a, a);

    
    // Turn on this anod.
    digitalWrite(anodPin, HIGH);   
    
    // Delay
    // NOTE: With the differnce in Nixie bulbs you may have to change
    //       this delay to set the update speed of the bulbs. If you 
    //       dont wait long enough the bulb will be dim or not light at all
    //       you want to set this delay just right so that you have 
    //       nice bright output yet quick enough so that you can multiplex with
    //       more bulbs.
    delay(delayVal);
      
    // Shut off this anod.
    digitalWrite(anodPin, LOW);

}

/**
 * DisplayNumberString
 * Purpose: passing an array that is 8 elements long will display numbers
 *          on a 6 nixie bulb setup.
 * @var array int* array containing the values for all 6 nixie tubes
 */
void DisplayNumberString (int* array) {
    
    // colons,
    DisplayNumberSet(0, 0, 0, 1);
    DisplayNumberSet(0, 1, 1, 1);
    DisplayNumberSet(0, 2, 2, 1);
    DisplayNumberSet(0, 3, 3, 1);
    
    // bank 1 (bulb 4, 8)
    DisplayNumberSet(1, array[3], array[7], 3.5f);
    // bank 2 (bulb 2, 7)
    DisplayNumberSet(2, array[2], array[6], 3.5f);
    // bank 3 (bulb 1, 5)
    DisplayNumberSet(3, array[1], array[5], 3.5f);
}

/**
 * Loop
 * Purpose: Main function that will continue to be executed as long as the system is energised
 */
void loop() {
    digitalWrite(ledPin_a_1, HIGH); // TEST
    // BT message
    char lastChar = '0'; // individual char message
   
    // Append data as it keeps arriving
    if(Serial.available()) {
       lastChar = Serial.read();
       data.concat(lastChar);
    }

    // check the frame is completed    
    if (data.length() == 5 && data.indexOf(",") != -1) {
        clockHourSet = atoi(data.substring(0, 2).c_str());
        clockMinSet = atoi(data.substring(3).c_str());
        data = "";
        lastChar = '0';
        Serial.read();
    }

    // Get milliseconds.
    runTime = millis();
    
    // Get time in seconds.
    long time = (runTime) / 1000;
    
    int hourInput = digitalRead(14);  
    int minInput  = digitalRead(15);

    if(hourInput == 0)
        HourButtonPressed = true;
    
    if(minInput == 0)
        MinButtonPressed = true;
    
    if(HourButtonPressed == true && hourInput == 1) {
        clockHourSet++;
        HourButtonPressed = false;
    }
    
    if(MinButtonPressed == true && minInput == 1) {
        clockMinSet++;
        MinButtonPressed = false;
    }
    
     // Set time based on offset..
    long hbump = 60*60*clockHourSet;
    long mbump = 60*clockMinSet;
    time += mbump + hbump;

    // Convert time to days,hours,mins,seconds
    long days  = time / DAYS;       time -= days  * DAYS; 
    long hours = time / HOURS;      time -= hours * HOURS; 
    long minutes  = time / MINS;    time -= minutes  * MINS; 
    long seconds  = time; 
    
    // Get the high and low order values for hours,min,seconds. 
    int lowerHours = hours % 10;
    int upperHours = hours - lowerHours;
    int lowerMins = minutes % 10;
    int upperMins = minutes - lowerMins;
    int lowerSeconds = seconds % 10;
    int upperSeconds = seconds - lowerSeconds;
    if (upperSeconds >= 10) upperSeconds = upperSeconds / 10;
    if (upperMins >= 10) upperMins = upperMins / 10;
    if (upperHours >= 10) upperHours = upperHours / 10;
 
    // Fill in the Number array used to display on the tubes.
    int NumberArray[8] = {0, 0, 0, 0, 0, 0, 0, 0};
    NumberArray[0] = 0; // colons
    NumberArray[1] = upperHours;
    NumberArray[2] = lowerHours;
    NumberArray[3] = upperMins;
    NumberArray[4] = 0; // colons, values of 0,1,2,3 make each dot brighter
    NumberArray[5] = lowerMins;
    NumberArray[6] = upperSeconds;
    NumberArray[7] = lowerSeconds;
    
    // Display.
    DisplayNumberString(NumberArray);
}

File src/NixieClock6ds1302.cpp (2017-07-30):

/**
 * Arduinix 6 Bulb ( IN-17 ) 
 * - Also supports Hour and Min. time set.
 *
 * This code runs a six bulb setup and displays a prototype clock setup.
 * NOTE: the delay is setup for IN-17 nixie bulbs.
 * by Jeremy Howa
 * www.robotpirate.com
 * www.arduinix.com
 * 2008 - 2009
 * Last Edit Aug 29, 2009
 *
 * NOTE: Major changes were basically formatting and pin selection based on my
 *       own PCB for the nixie tubes (NH-12A)
 * @author Matias Quintana matiasquitana.com
 * @version 16/01/17
 */

/**
 * SN74141: True Table
 * D  C  B  A  #     
 * L, L, L, L  0
 * L, L, L, H  1
 * L, L, H, L  2
 * L, L, H, H  3
 * L, H, L, L  4
 * L, H, L, H  5
 * L, H, H, L  6
 * L, H, H, H  7
 * H, L, L, L  8
 * H, L, L, H  9
 */

// Debug mode for sending the current time via serial 
#define DEBUG_ON true

/** Pin mapping for ADC, Arduino UNO, Atmega328P
 * ARDUINO UNO    Atmega328P
 *     PIN2          PD2
 *     PIN3          PD3
 *     PIN4          PD4
 *     PIN5          PD5
 *     PIN6          PD6
 *     PIN7          PD7
 *     PIN8          PB0
 *     PIN9          PB1
 *    PIN10          PB2
 *    PIN11          PB3
 *    PIN12          PB4
 *    PIN14          PC0
 *    PIN15          PC1
 */

/**
 * setup()
 * Purpose: IO initialization and debugging flag set
 */
void setup() {
    // SN74141 (1)
    // Output: PD2:PD5
    // PD2 = a, PD3 = b, PD4 = c, PD5 = d
    DDRD |= 0b11111100;
    // SN74141 (2)
    // Output: PD6:PD7 and PB0:PB1
    // PD6 = a, PD7 = b, PB0 = c, PB1 = d
    DDRB |= 0b00011111;
    // Anode pins:PB2:PB4
    // PB2: anode1
    // PB3: anode2
    // PB4: anode3

    // The following pins can be wired to buttons
    // Grounding on pins PC0 and PC1 will set the Hour and Mins.
    // Input: PC0:PC1
    DDRC |= 0b00000000;
    // Set pull up resistors in those pins
    PORTC |= 0b00000011;  
  
    if (DEBUG_ON) {
        Serial.begin(9600);
    }
}

/**
 * DisplayNumberSet
 * Purpose: Looks up the truth table and opens the correct outs from the arduino
 * to light the numbers given to this funciton (num1,num2), on a 6 nixie bulb setup. 
 * @var anod anode number
 * @var num1 bulb 1 value
 * @var num2 bulb 2 value
 **/
void DisplayNumberSet (int anod, int num1, int num2) {
    int a,b,c,d;

    // set defaults.
    a = 0; b = 0; c = 0; d = 0; // will display a zero.
  
    // Load the a,b,c,d.. to send to the SN74141 IC (1)
    switch (num1) {
        case 0: a = 0; b = 0; c = 0; d = 0; break;
        case 1: a = 1; b = 0; c = 0; d = 0; break;
        case 2: a = 0; b = 1; c = 0; d = 0; break;
        case 3: a = 1; b = 1; c = 0; d = 0; break;
        case 4: a = 0; b = 0; c = 1; d = 0; break;
        case 5: a = 1; b = 0; c = 1; d = 0; break;
        case 6: a = 0; b = 1; c = 1; d = 0; break;
        case 7: a = 1; b = 1; c = 1; d = 0; break;
        case 8: a = 0; b = 0; c = 0; d = 1; break;
        case 9: a = 1; b = 0; c = 0; d = 1; break;
    }    
    
    // Write the value in SN74141 (1)
    // set nth bit to value x
    // number = number & ~(1 << n) | (x << n);
    PORTD = PIND & ~(1 << PD5) | (d << PD5); // d
    PORTD = PIND & ~(1 << PD4) | (c << PD4); // c
    PORTD = PIND & ~(1 << PD3) | (b << PD3); // b
    PORTD = PIND & ~(1 << PD2) | (a << PD2); // a

    // Load the a,b,c,d.. to send to the SN74141 IC (2)
    switch (num2) {
        case 0: a = 0; b = 0; c = 0; d = 0; break;
        case 1: a = 1; b = 0; c = 0; d = 0; break;
        case 2: a = 0; b = 1; c = 0; d = 0; break;
        case 3: a = 1; b = 1; c = 0; d = 0; break;
        case 4: a = 0; b = 0; c = 1; d = 0; break;
        case 5: a = 1; b = 0; c = 1; d = 0; break;
        case 6: a = 0; b = 1; c = 1; d = 0; break;
        case 7: a = 1; b = 1; c = 1; d = 0; break;
        case 8: a = 0; b = 0; c = 0; d = 1; break;
        case 9: a = 1; b = 0; c = 0; d = 1; break;
    }

    // Write the value in SN74141 (2)
    PORTB = PINB & ~(1 << PB1) | (d << PB1); // d
    PORTB = PINB & ~(1 << PB0) | (c << PB0); // c
    PORTD = PIND & ~(1 << PD7) | (b << PD7); // b
    PORTD = PIND & ~(1 << PD6) | (a << PD6); // a

    // Select what node to fire and turn on that node (HIGH)
    switch (anod) {
        case 0: PORTB |= 1 << PB2; break;
        case 1: PORTB |= 1 << PB3; break;
        case 2: PORTB |= 1 << PB4; break;
    }

    // Delay
    // NOTE: With the differnce in Nixie bulbs you may have to change
    //       this delay to set the update speed of the bulbs. If you 
    //       dont wait long enough the bulb will be dim or not light at all
    //       you want to set this delay just right so that you have 
    //       nice bright output yet quick enough so that you can multiplex with
    //       more bulbs.
    delay(2);
  
    switch (anod) { // Turn off this anode (LOW)
        case 0: PORTB &= ~(1 << PB2); break;
        case 1: PORTB &= ~(1 << PB3); break;
        case 2: PORTB &= ~(1 << PB4); break;
    }
}

/**
 * DisplayNumberString
 * Purpose: passing an array that is 8 elements long will display numbers
 *          on a 6 nixie bulb setup.
 * @var array int* array containing the values for all 6 nixie tubes
 */
void DisplayNumberString (int* array) {
    // bank 1 (bulb 0, 3)
    DisplayNumberSet(0, array[0], array[3]);
    // bank 2 (bulb 1, 4)
    DisplayNumberSet(1, array[4], array[1]); //it should be (1, array[1], array[4]) but there was a mistake in the first PCB
    // bank 3 (bulb 2, 5)
    DisplayNumberSet(2, array[2], array[5]);   
}

// DEFINE
long MINS  = 60;         // 60 Seconds in a Min.
long HOURS = 60 * MINS;  // 60 Mins in an hour.
long DAYS  = 12 * HOURS; // 24 Hours in a day. > Note: change the 24 to a 12 for non millitary time.

long runTime = 0;        // Time from when we started.

// default time sets. clock will start at the indicated values below clockHourSet:clockMinSet:00
// NOTE: Seconds start at 0
long clockHourSet = 12;
long clockMinSet  = 34;

int HourButtonPressed = false;
int MinButtonPressed = false;
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

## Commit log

2017-07-30 First upload of existing files
    [ArduiNIX_Shield_v3.brd, ArduiNIX_Shield_v3.sch, ArduiNIX_Shield_v3_modified.brd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]
2018-04-22 added RTC code. Microcontroller can read time from the RTC and use that as baseline for keeping track of time
2018-04-22 rearranged file structures and documents
    [ArduiNIX_Shield_v3.brd, ArduiNIX_Shield_v3.sch, ArduiNIX_Shield_v3_modified.brd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]
2018-05-27 rearranged file structures and added files to .gitignore
    [arduino_Uno_mod.brd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]
2018-12-29 added only bluetooth version
    [.GBL, .GBO, .GBS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]
2019-03-12 updated android app to handle BLE 4.0
    [ArduiNIX_Shield_v3.sch, arduino_Uno_mod_bt.brd, arduino_Uno_mod_bt.sch]
